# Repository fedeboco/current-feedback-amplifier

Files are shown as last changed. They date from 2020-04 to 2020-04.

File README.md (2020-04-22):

# Current Feedback Topology 40W Audio Amplifier

The current feedback topology gives this amplifier some independency between gain and bandwidth, resulting in an amplifier with relatively high power and high bandwidth (around 450 kHz at full power). Having a higher bandwidth than the traditional audio band (up to 20 kHz) produces a lower phase distortion in the audio band, consequently producing better sound.

##### Specifications achieved:
| Specification | Measured  |
| --- | -----: |
| Power (RMS) | 40 W |
| Power Bandwidth | 450 kHz |
| Bandwidth | 1MHz |
| SNR | 84 dB |
| THD (40W) | 0.2% |
| THD (1W) | 0.012% |
| IMD (1W) | -78 dB |
| Gain | 24.5 dB |

## Design

Heatsink has been designed using FreeCad and circuit using KiCad.

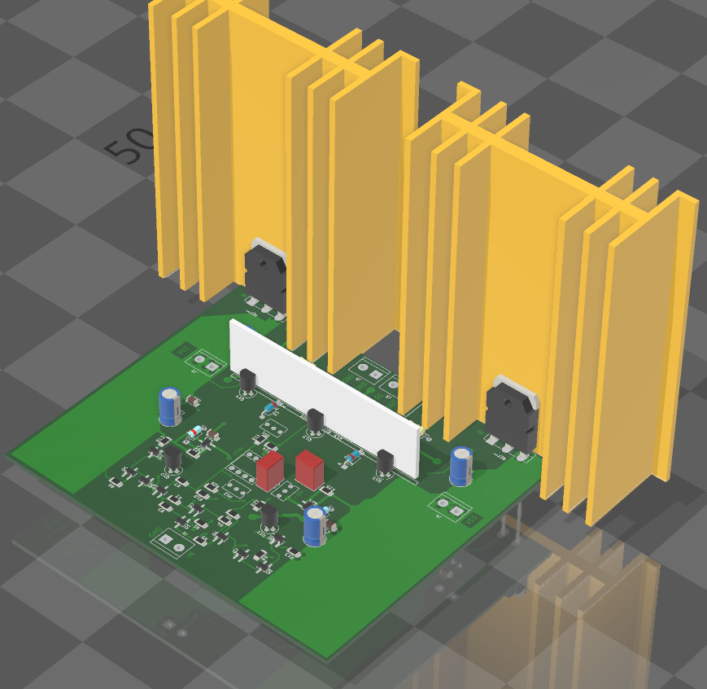
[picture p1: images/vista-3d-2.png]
![]()

## Schematic

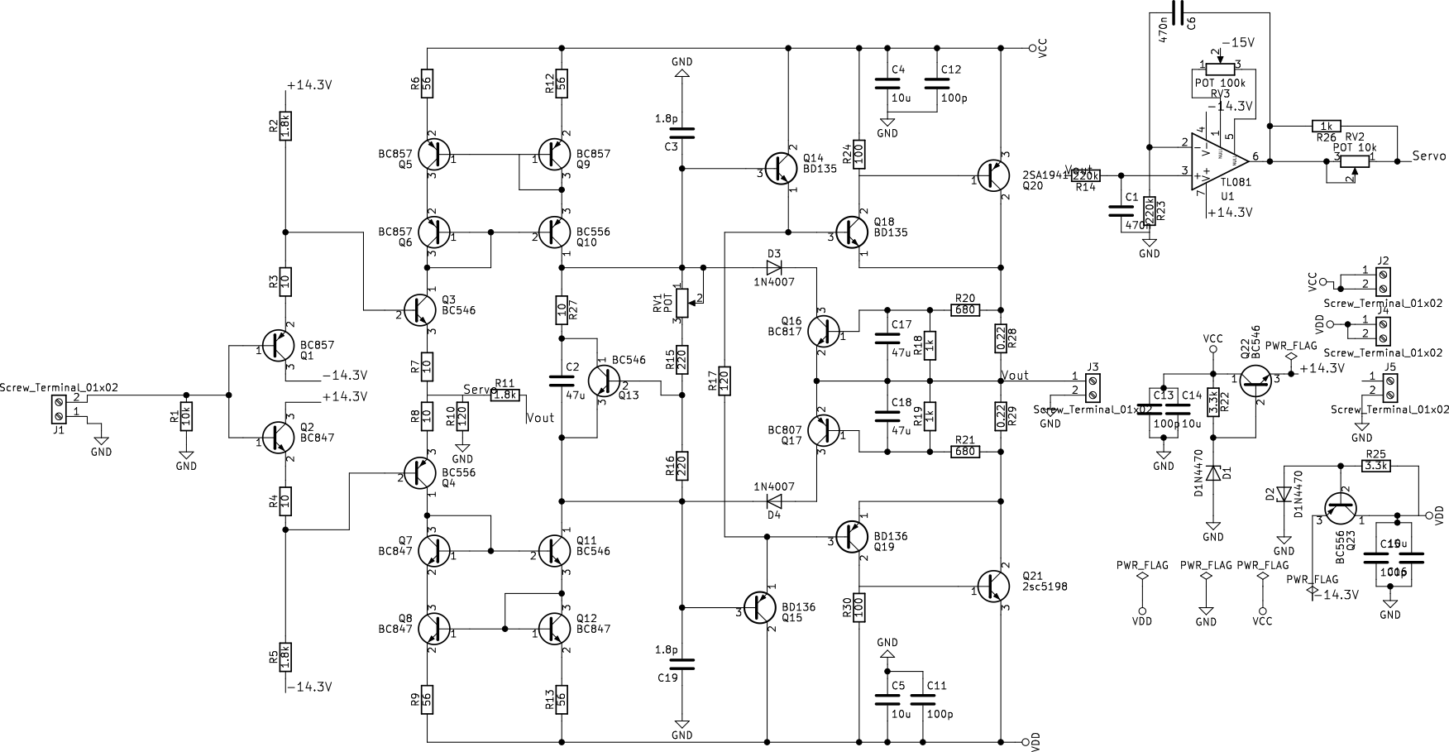
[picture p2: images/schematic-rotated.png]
![]()

## Total Harmonic Distortion Measured

Distortion did not exceed 0,2% at full power, rating at around 0,1% on average of frequencies.

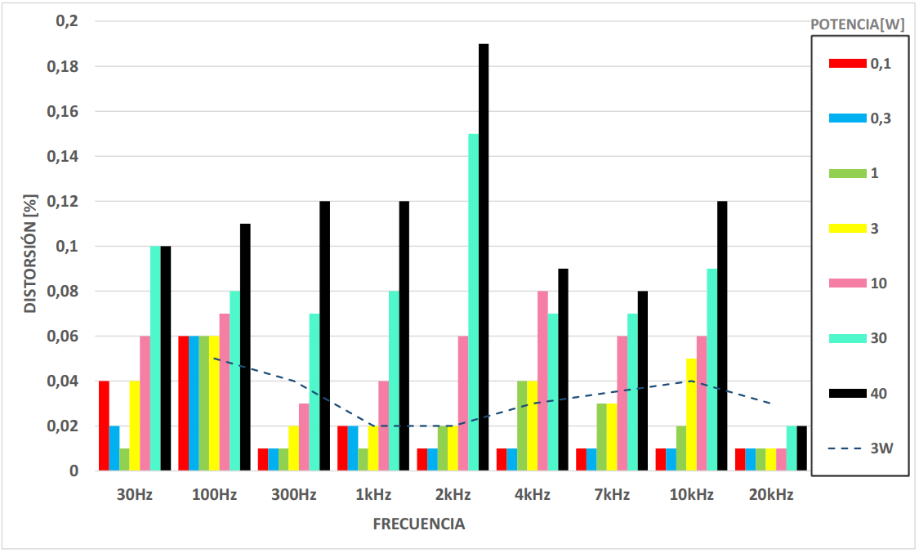
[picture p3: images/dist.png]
![]()

## Different views and base

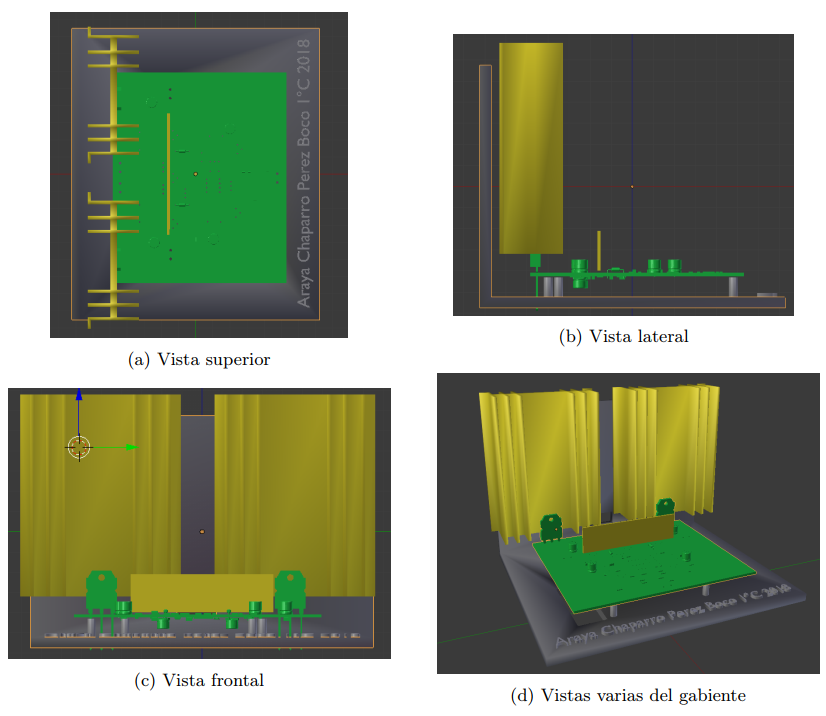
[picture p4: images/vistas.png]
![]()

## Previous Version

This version was bigger than the current version. It was also difficult to measure, more unstable and produced higher temperatures.

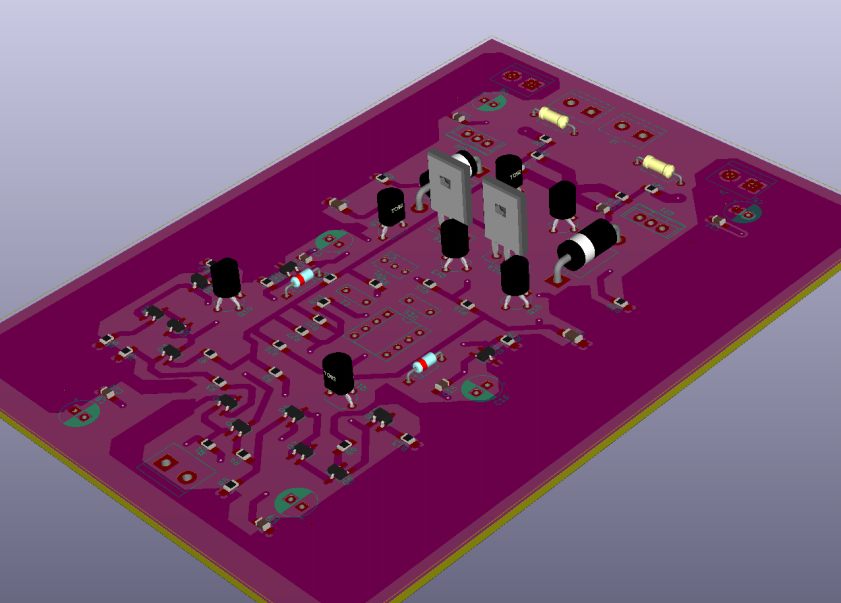
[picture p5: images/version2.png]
![]()

## PCB

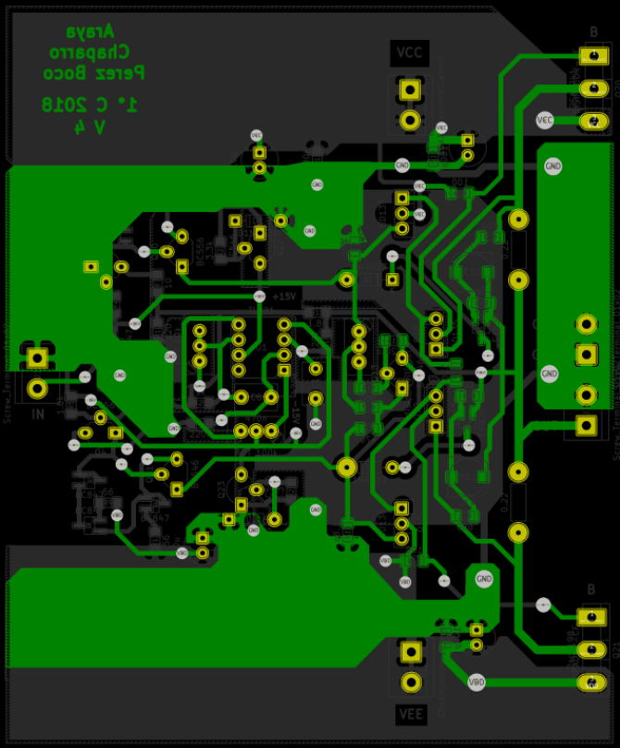
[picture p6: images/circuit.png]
![]()

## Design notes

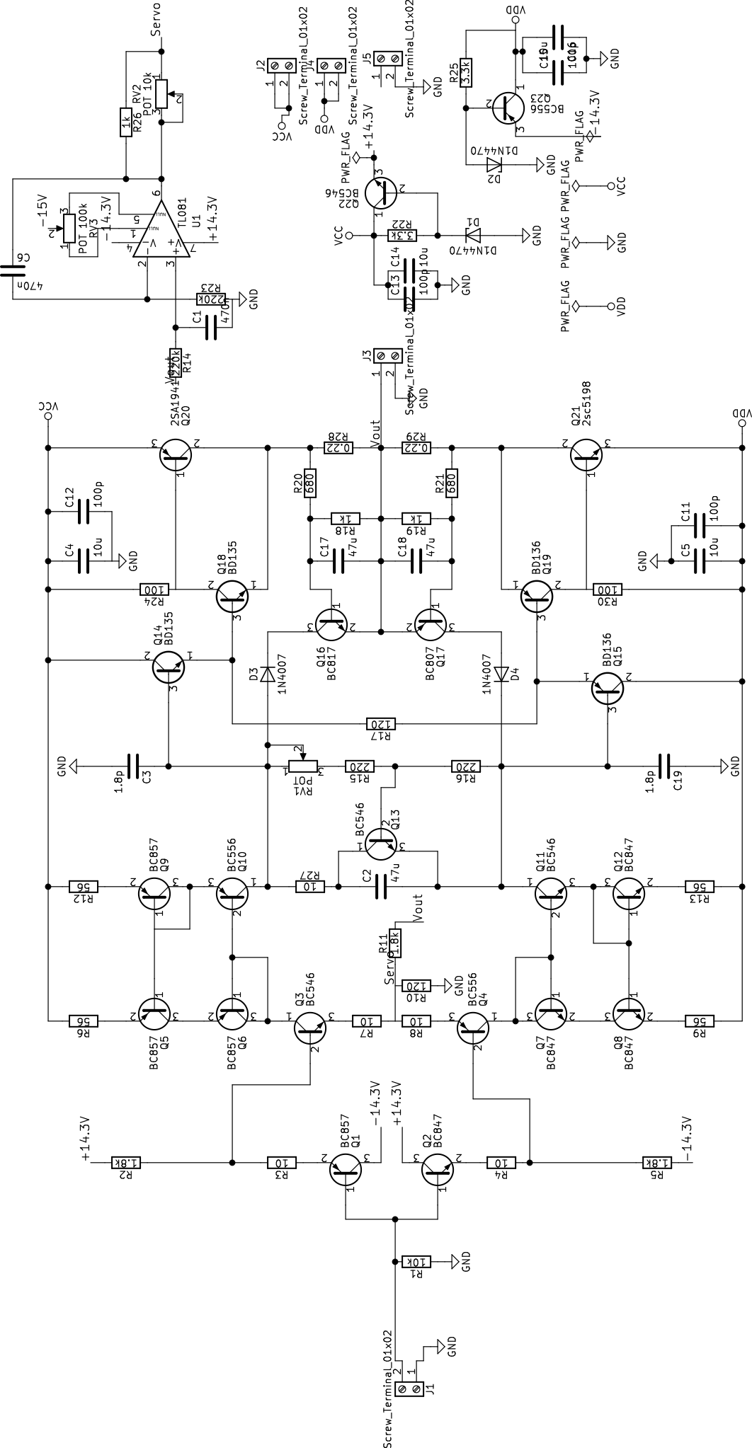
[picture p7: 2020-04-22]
images/schematic.png

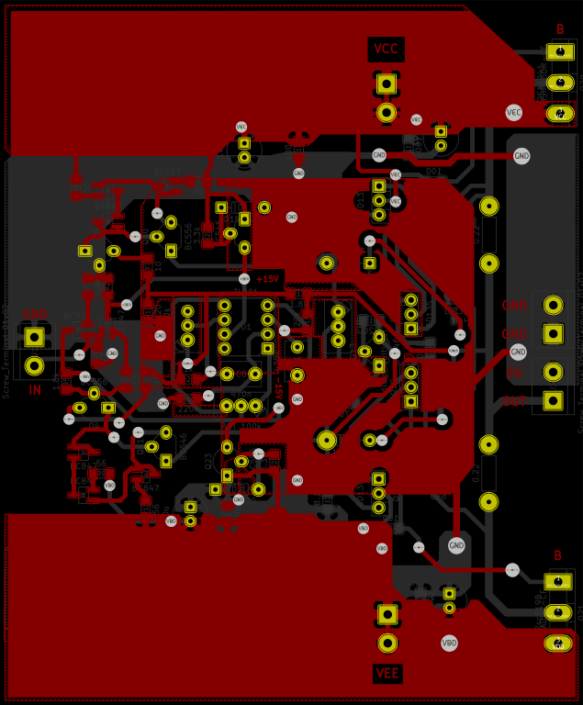
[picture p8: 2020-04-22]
schematic/VISTASUPERIOR.png

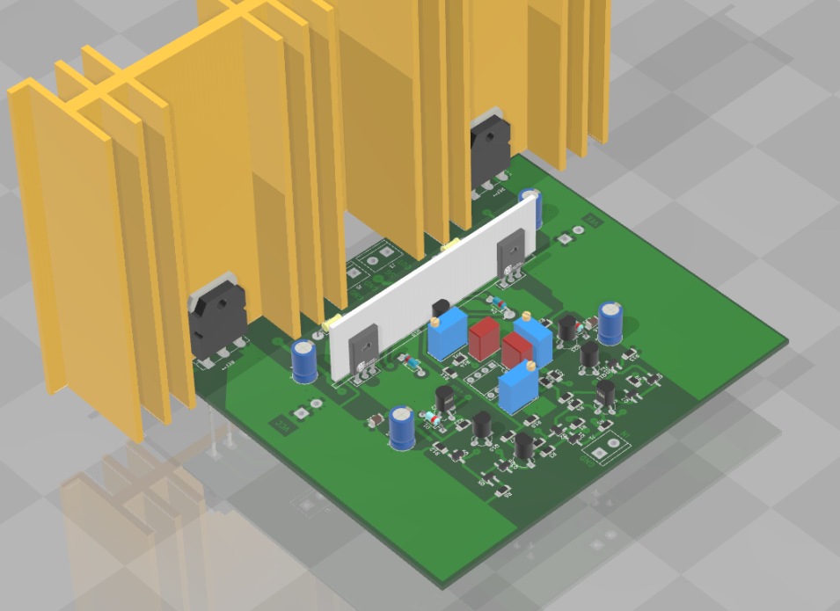
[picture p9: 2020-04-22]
images/vista-3d.png

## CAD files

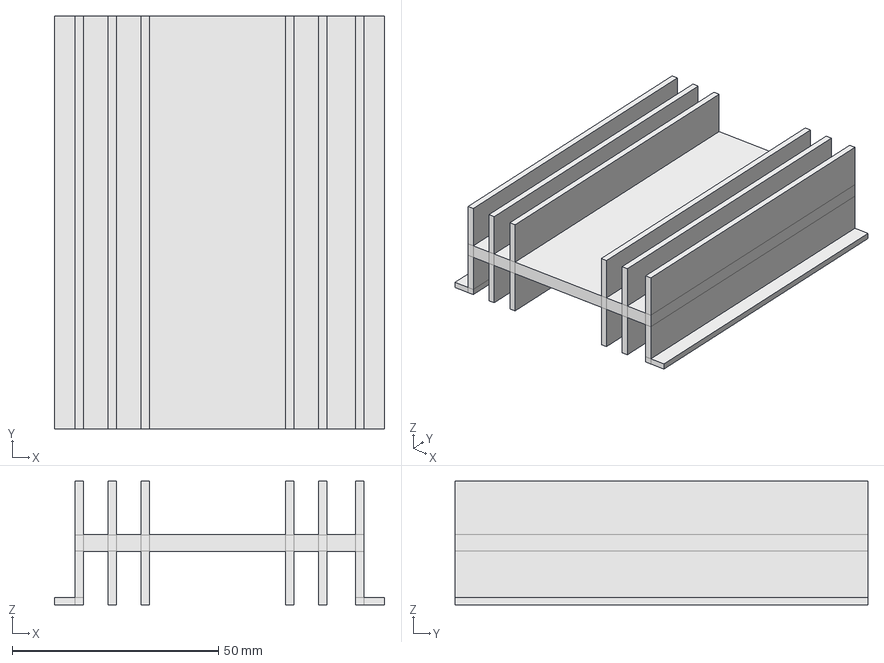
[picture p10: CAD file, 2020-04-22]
schematic/DISIPADOR/Disipador.FCStd
80.0 x 100.0 x 30.0 mm

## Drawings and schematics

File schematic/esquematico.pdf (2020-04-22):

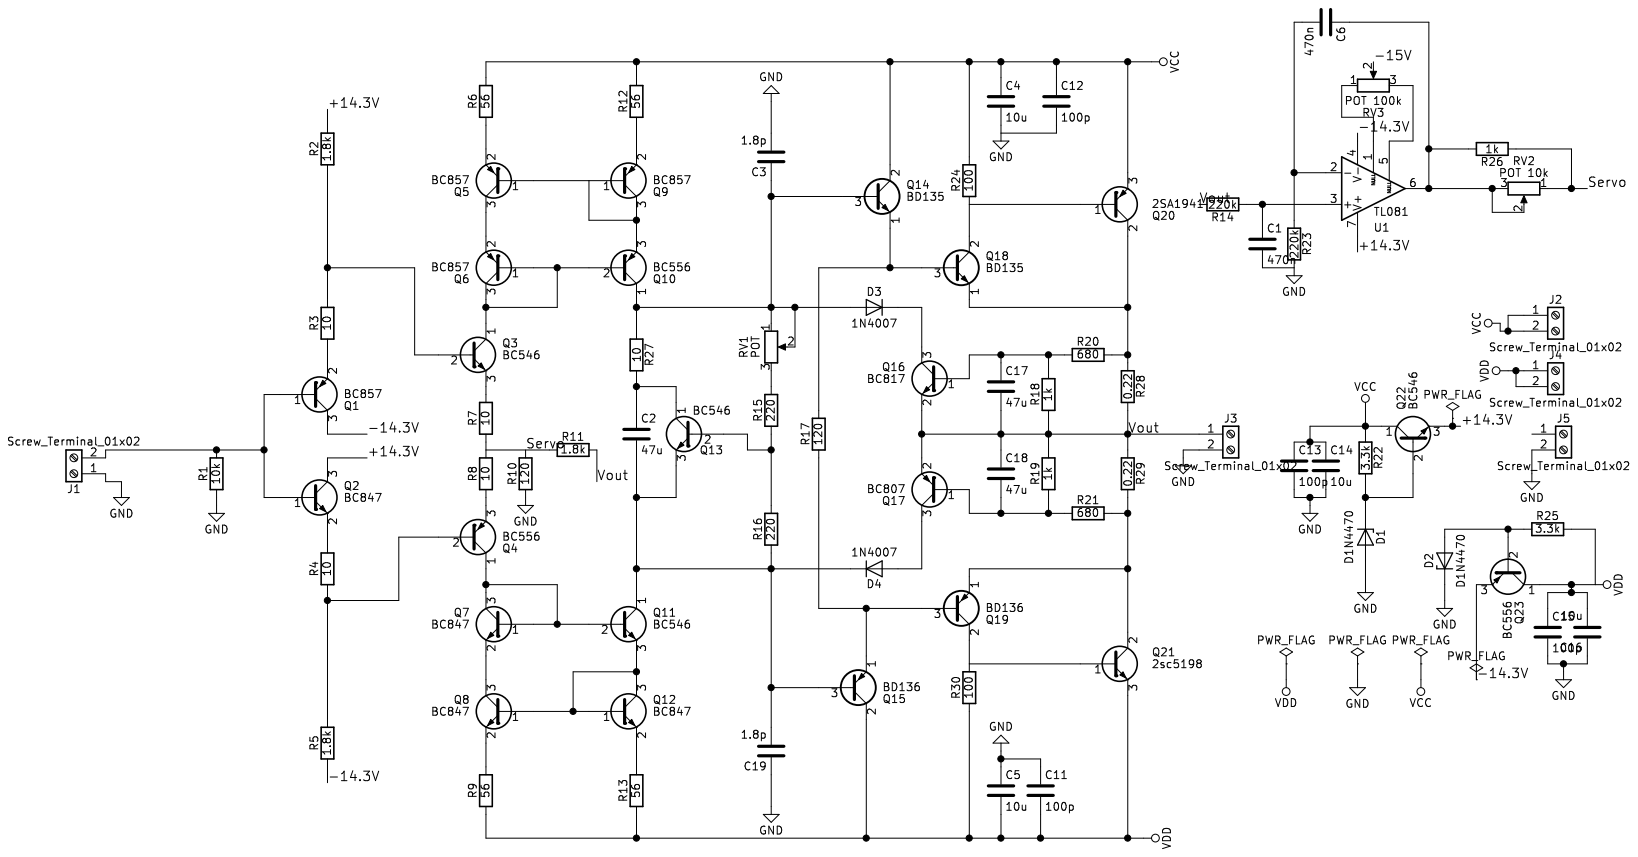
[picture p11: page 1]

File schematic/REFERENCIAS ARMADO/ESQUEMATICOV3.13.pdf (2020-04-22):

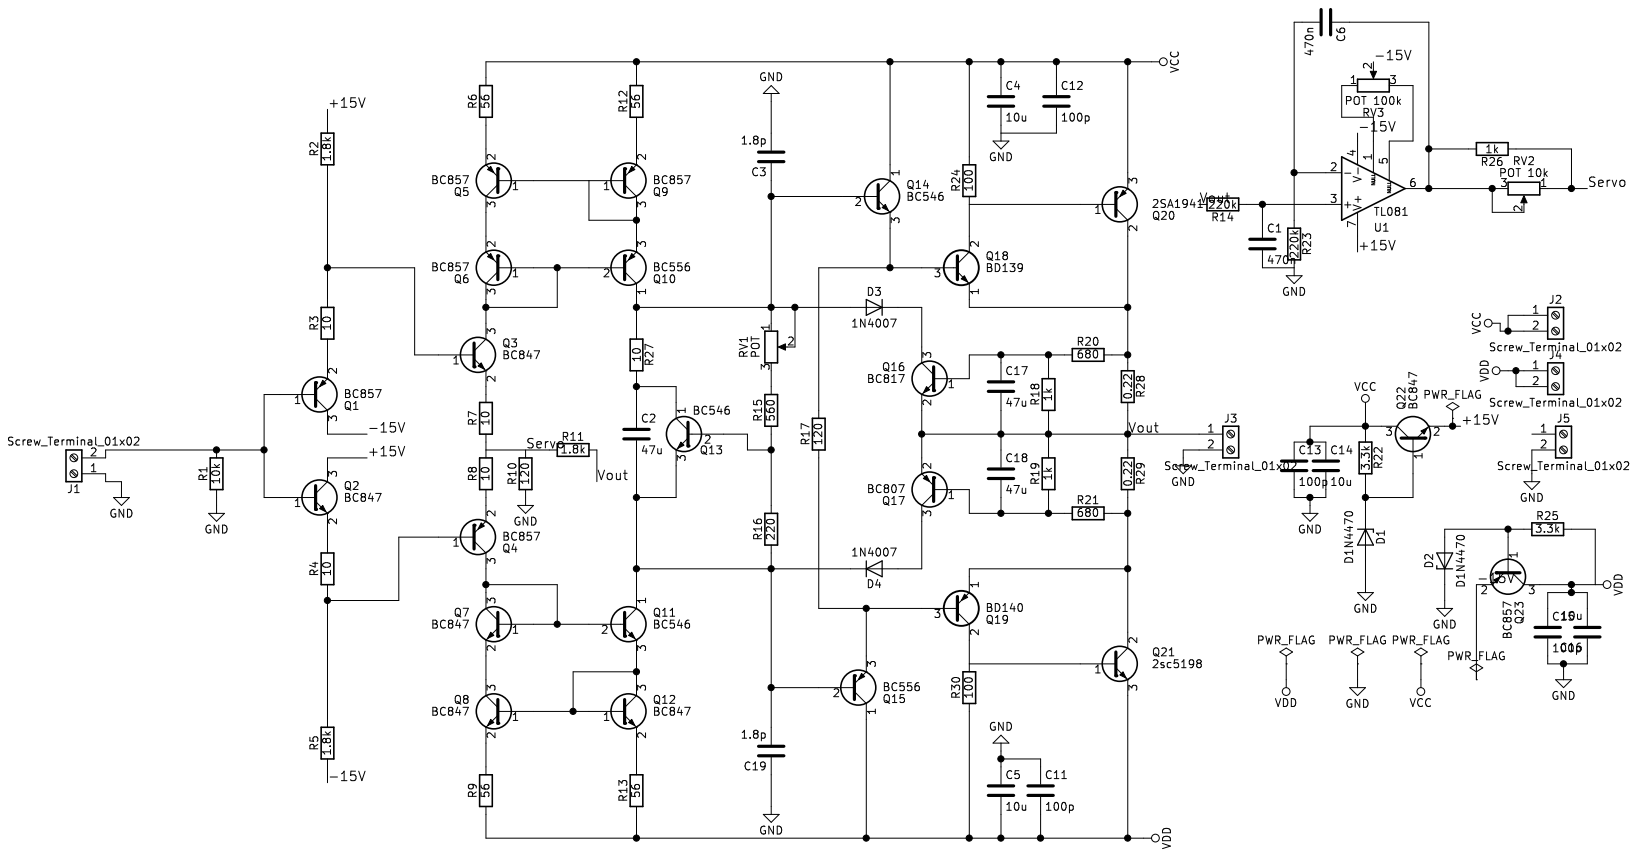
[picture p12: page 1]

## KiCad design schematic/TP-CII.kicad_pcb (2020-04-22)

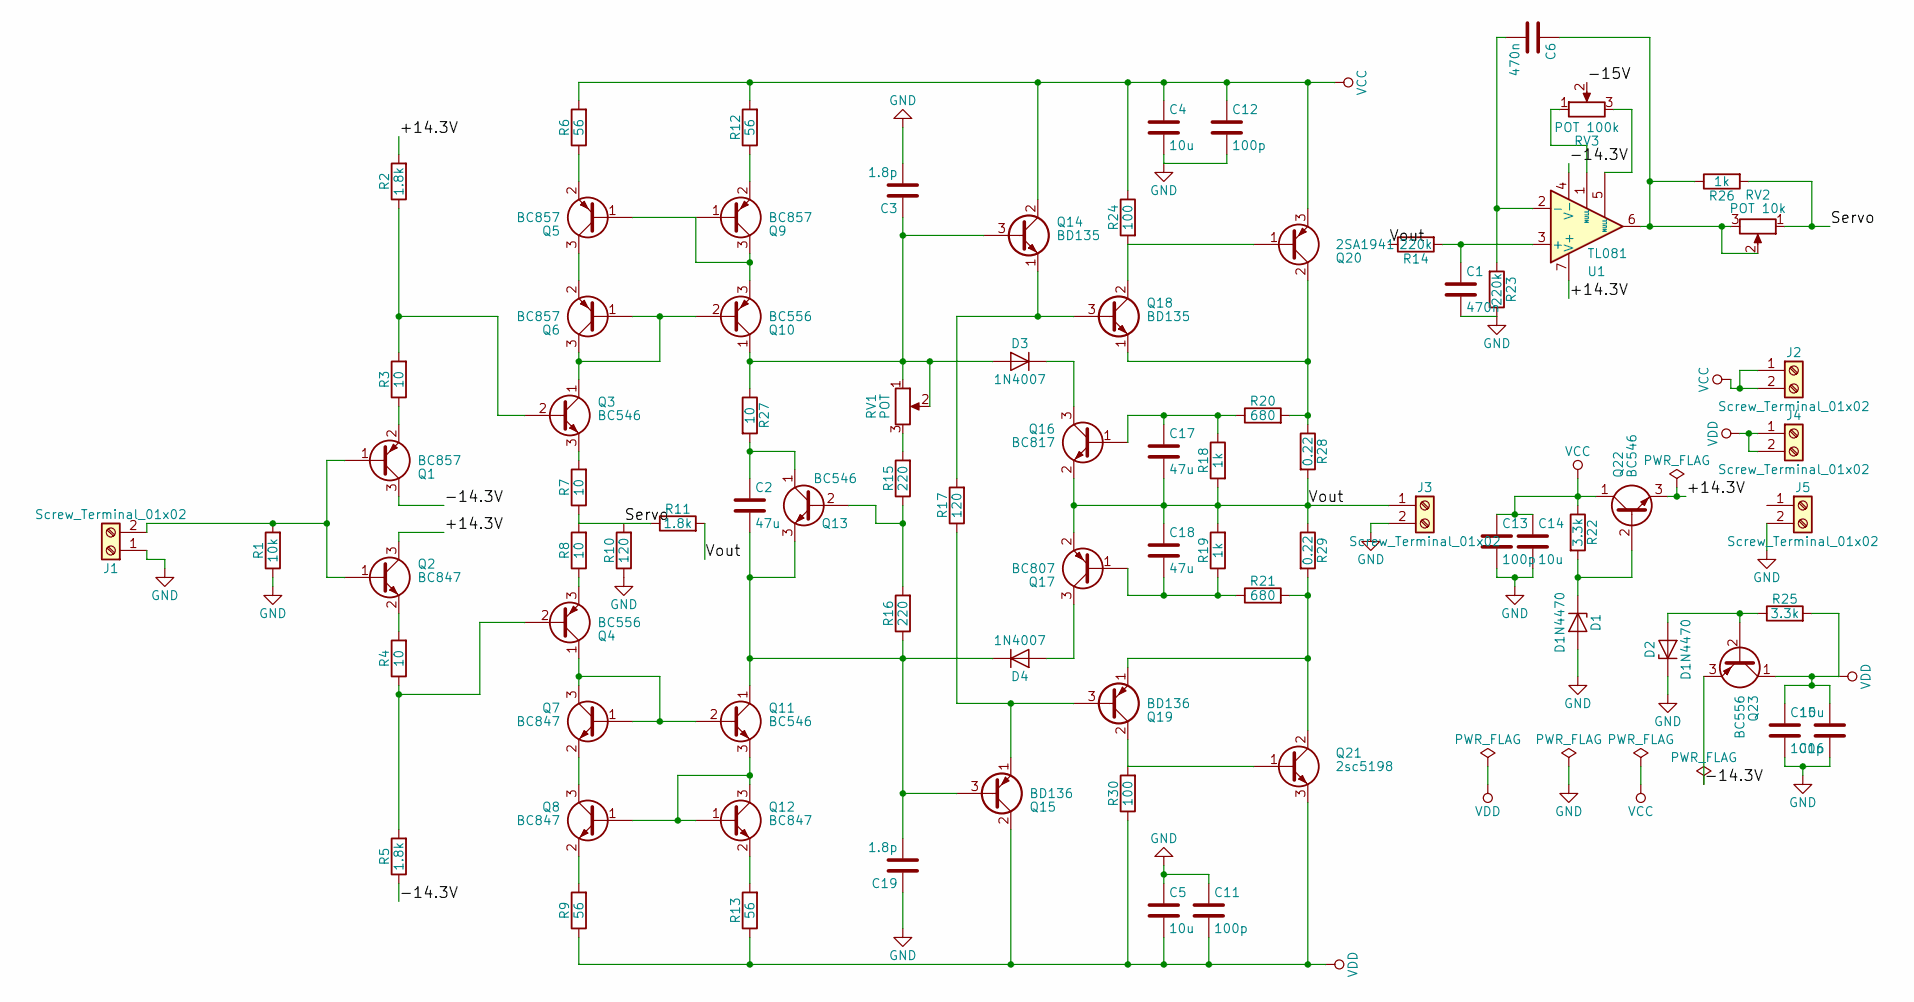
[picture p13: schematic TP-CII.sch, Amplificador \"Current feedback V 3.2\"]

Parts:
C1, C6: 470n; C_Rect_L9.0mm_W4.0mm_P7.50mm_MKT
C2: 47u; C_1206_3216Metric_Pad1.42x1.75mm_HandSolder
C3, C19: 1.8p; C_1206_3216Metric_Pad1.42x1.75mm_HandSolder
C4, C5, C14, C16: 10u; CP_Radial_D6.3mm_P2.50mm
C11, C12, C13, C15: 100p; C_1206_3216Metric_Pad1.42x1.75mm_HandSolder
C17, C18: 47u; CP_Elec_6.3x5.7
D1, D2: D1N4470; D_DO-35_SOD27_P7.62mm_Horizontal
D3, D4: 1N4007; D_DO-35_SOD27_P7.62mm_Horizontal
J1, J2, J3, J4, J5: Screw_Terminal_01x02; TerminalBlock_bornier-2_P5.08mm
Q1, Q5, Q6: BC857; TSOT-23_HandSoldering
Q2, Q7, Q8: BC847; TSOT-23_HandSoldering
Q3, Q11, Q13, Q22: BC546; TO-92
Q4, Q10, Q23: BC556; TO-92
Q9: BC857; SOT-23_Handsoldering
Q12: BC847; SOT-23_Handsoldering
Q14, Q18: BD135; TO-126_Vertical
Q15, Q19: BD136; TO-126_Vertical
Q16: BC817; TSOT-23_HandSoldering
Q17: BC807; TSOT-23_HandSoldering
Q20: 2SA1941; TO-3P-3_Vertical
Q21: 2sc5198; TO-3P-3_Vertical
R1: 10k; R_1206_3216Metric_Pad1.42x1.75mm_HandSolder
R2, R5, R11: 1.8k; R_1206_3216Metric_Pad1.42x1.75mm_HandSolder
R3, R4, R7, R8, R27: 10; R_1206_3216Metric_Pad1.42x1.75mm_HandSolder
R6, R9, R12, R13: 56; R_1206_3216Metric_Pad1.42x1.75mm_HandSolder
R10, R17: 120; R_1206_3216Metric_Pad1.42x1.75mm_HandSolder
R14, R23: 220k; R_1206_3216Metric_Pad1.42x1.75mm_HandSolder
R15, R16: 220; R_1206_3216Metric_Pad1.42x1.75mm_HandSolder
R18, R19, R26: 1k; R_1206_3216Metric_Pad1.42x1.75mm_HandSolder
R20, R21: 680; R_1206_3216Metric_Pad1.42x1.75mm_HandSolder
R22, R25: 3.3k; R_1206_3216Metric_Pad1.42x1.75mm_HandSolder
R24, R30: 100; R_1206_3216Metric_Pad1.42x1.75mm_HandSolder
R28, R29: 0.22; R_Axial_DIN0207_L6.3mm_D2.5mm_P10.16mm_Horizontal
RV1: POT; Potentiometer_Bourns_3266Y_Vertical
RV2: POT 10k; Potentiometer_Bourns_3266Y_Vertical
RV3: POT 100k; Potentiometer_Bourns_3266Y_Vertical
U1: TL081; DIP-8_W7.62mm_Socket

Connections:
/+15V: Q2.3 (C), Q22.3 (E), R2.2, U1.7 (V+)
/Servo: R7.1, R8.2, R10.2, R11.1, R26.2, RV2.1
/Vout: C17.2, C18.1, J3.1, Q16.2 (E), Q17.2 (E), R11.2, R14.1, R18.2, R19.2, R28.2, R29.1
GND: C1.2, C3.2, C4.2, C5.1, C11.1, C12.2, C13.2, C14.2, C15.2, C16.1, C19.1, D1.2 (A), D2.1 (K), J1.1, J3.2, J5.2, R1.1, R10.1, R23.1; also elsewhere on the board
unnamed: C1.1, R14.2, U1.3 (+)
unnamed: C2.1, Q13.1 (C), R27.2
unnamed: C3.1, D3.2 (A), Q10.1 (C), Q14.3 (B), R27.1, RV1.1, RV1.2
unnamed: C6.1, R26.1, RV2.2, RV2.3, U1.6
unnamed: C6.2, R23.2, U1.2 (-)
unnamed: C17.1, Q16.1 (B), R18.1, R20.1
unnamed: C18.2, Q17.1 (B), R19.1, R21.1
unnamed: C2.2, C19.2, D4.1 (K), Q11.1 (C), Q13.3 (E), Q15.3 (B), R16.1
unnamed: D1.1 (K), Q22.2 (B), R22.2
unnamed: D2.2 (A), Q23.2 (B), R25.1
unnamed: D3.1 (K), Q16.3 (C)
unnamed: D4.2 (A), Q17.3 (C)
unnamed: J1.2, Q1.1 (B), Q2.1 (B), R1.2
unnamed: Q1.2 (E), R3.1
unnamed: Q2.2 (E), R4.2
unnamed: Q3.2 (B), R2.1, R3.2
unnamed: Q3.3 (E), R7.2
unnamed: Q4.2 (B), R4.1, R5.2
unnamed: Q4.3 (E), R8.1
unnamed: Q5.2 (E), R6.1
unnamed: Q5.3 (C), Q6.2 (E)
unnamed: Q7.2 (E), Q8.3 (C)
unnamed: Q8.2 (E), R9.2
unnamed: Q9.2 (E), R12.1
unnamed: Q3.1 (C), Q6.1 (B), Q6.3 (C), Q10.2 (B)
unnamed: Q5.1 (B), Q9.1 (B), Q9.3 (C), Q10.3 (E)
unnamed: Q4.1 (C), Q7.1 (B), Q7.3 (C), Q11.2 (B)
unnamed: Q8.1 (B), Q11.3 (E), Q12.1 (B), Q12.3 (C)
unnamed: Q12.2 (E), R13.2
unnamed: Q13.2 (B), R15.1, R16.2
unnamed: Q14.1 (E), Q18.3 (B), R17.2
unnamed: Q15.1 (E), Q19.3 (B), R17.1
unnamed: Q18.1 (E), Q20.2 (C), R20.2, R28.1
unnamed: Q18.2 (C), Q20.1 (B), R24.2
unnamed: Q19.1 (E), Q21.2 (C), R21.2, R29.2
unnamed: Q19.2 (C), Q21.1 (B), R30.2
unnamed: R15.2, RV1.3
unnamed: RV3.1, U1.1 (NULL)
unnamed: RV3.3, U1.5 (NULL)
VCC: C4.1, C12.1, C13.1, C14.1, J2.1, J2.2, Q14.2 (C), Q20.3 (E), Q22.1 (C), R6.2, R12.2, R22.1, R24.1; also elsewhere on the board
VDD: C5.2, C11.2, C15.1, C16.2, J4.1, J4.2, Q15.2 (C), Q21.3 (E), Q23.1 (C), R9.1, R13.1, R25.2, R30.1

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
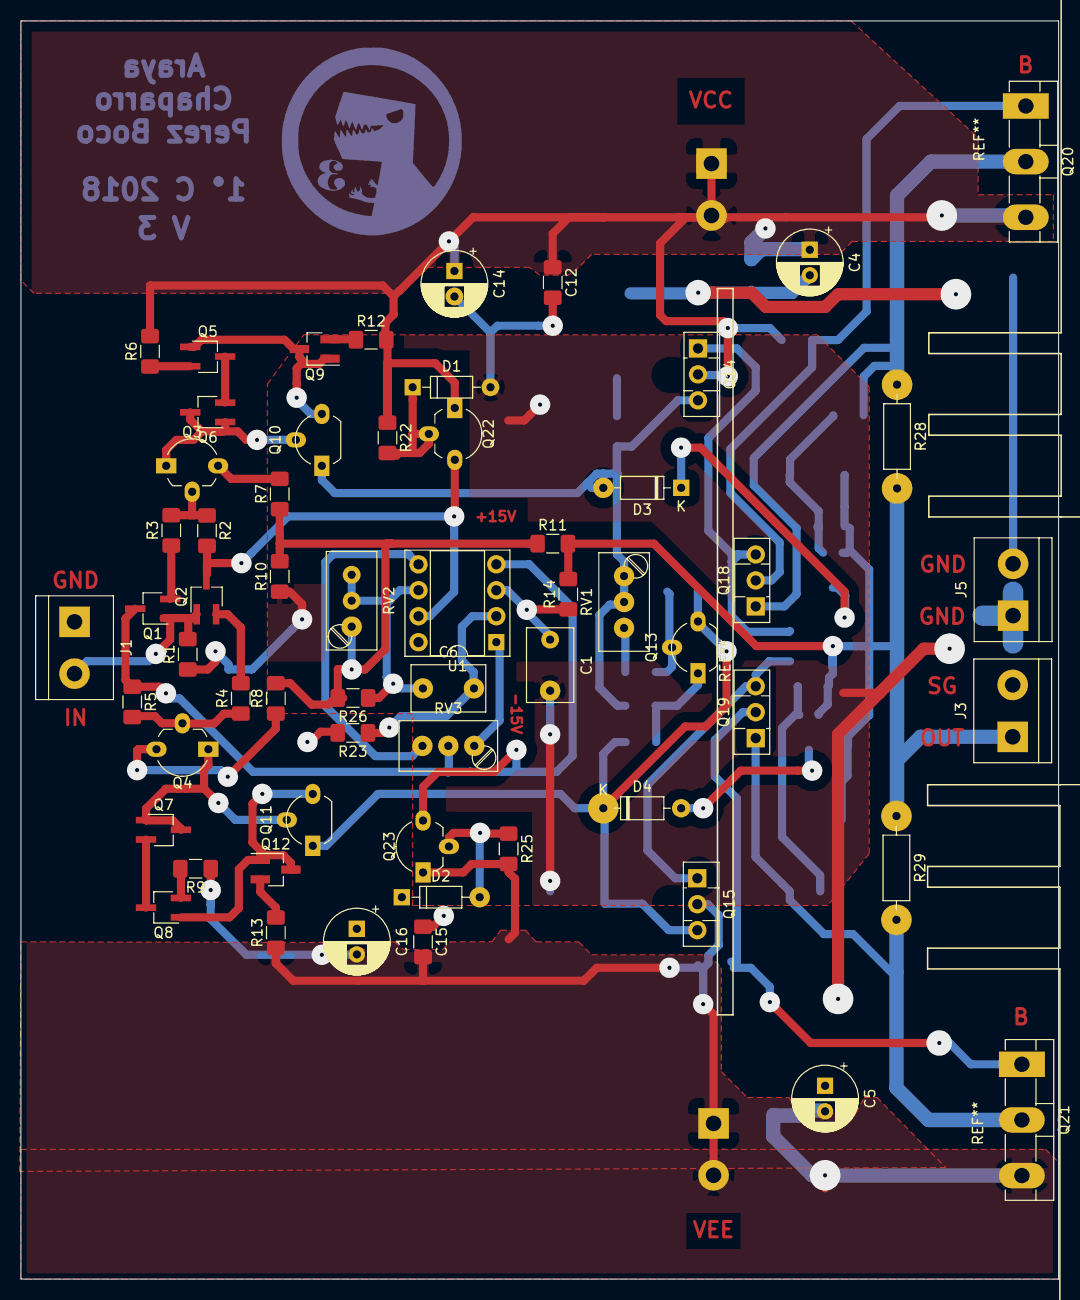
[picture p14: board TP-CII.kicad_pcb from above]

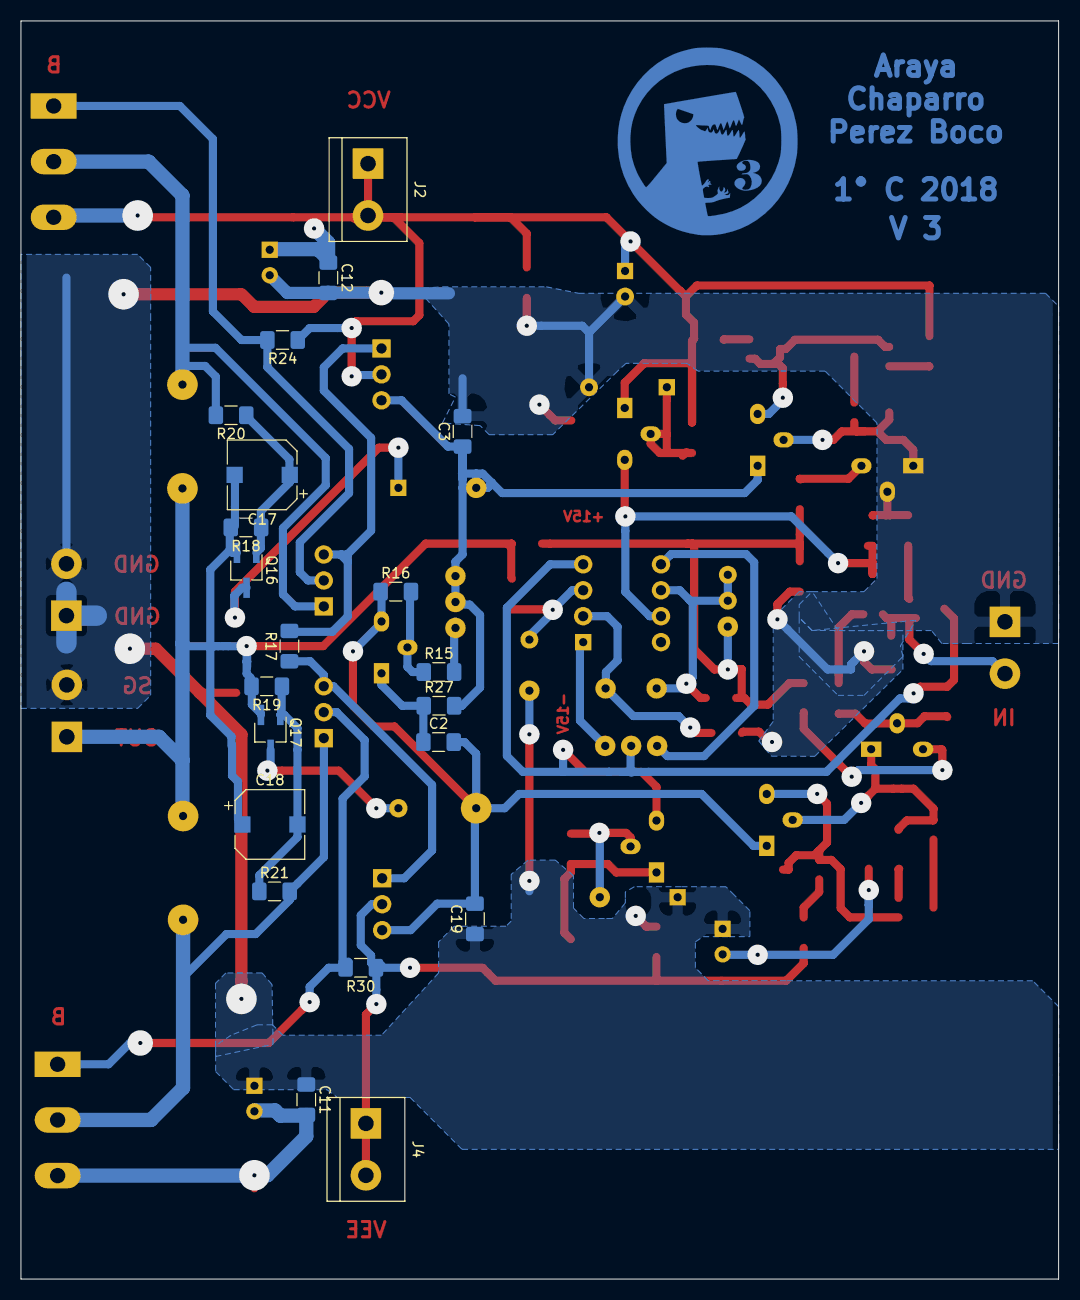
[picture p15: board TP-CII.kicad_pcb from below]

Board: 2 copper layers, 101.6 x 123.2 mm, 81 parts (21 on the bottom side), 46 nets.

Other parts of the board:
C12#2: 100p; C_1206_3216Metric_Pad1.42x1.75mm_HandSolder

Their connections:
GND: C12#2.2; also elsewhere on the board
VCC: C12#2.1; also elsewhere on the board

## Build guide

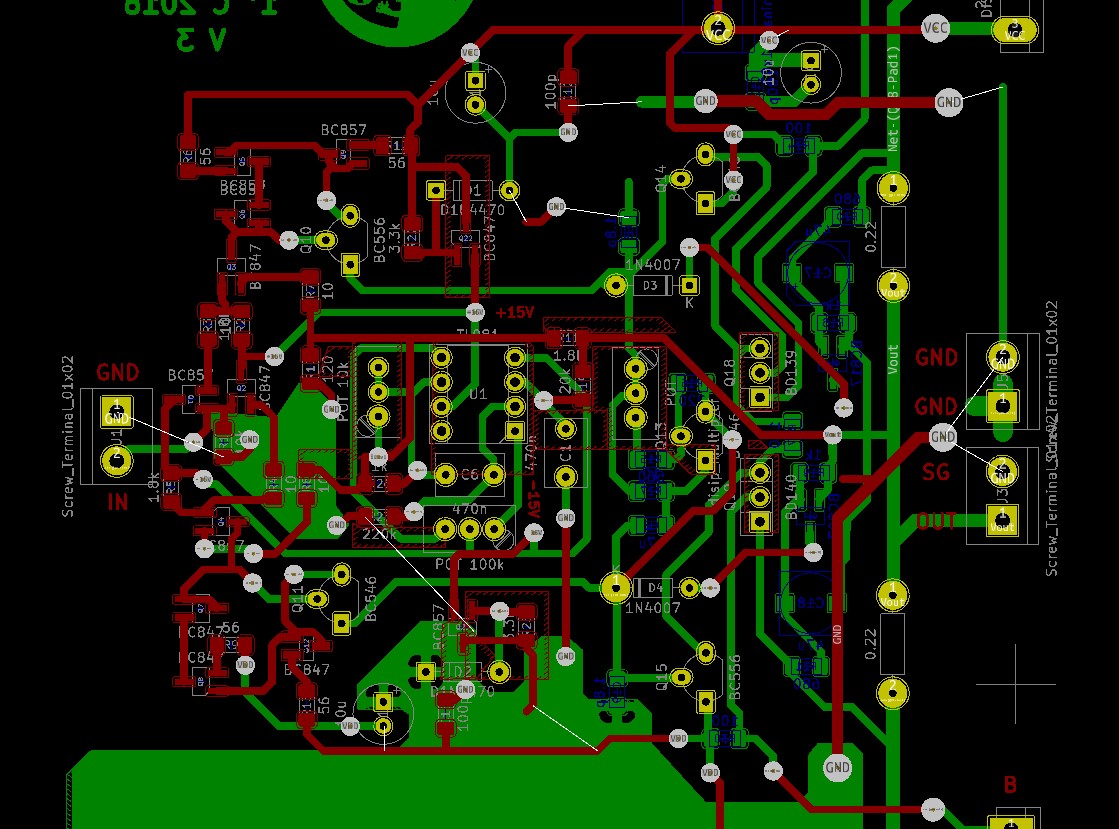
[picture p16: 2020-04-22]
schematic/REFERENCIAS ARMADO/VISTAPCBV3.13.jpg

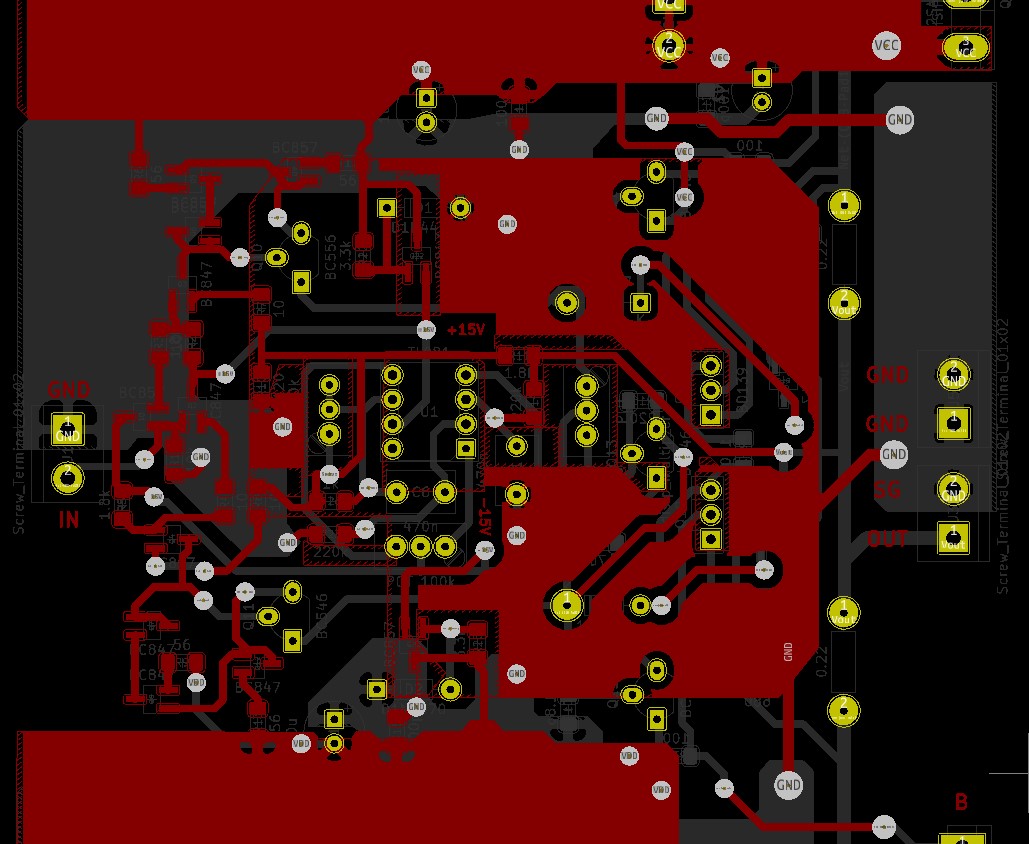
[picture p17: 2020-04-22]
schematic/REFERENCIAS ARMADO/VISTAPCBHCFRONTV3.13.jpg

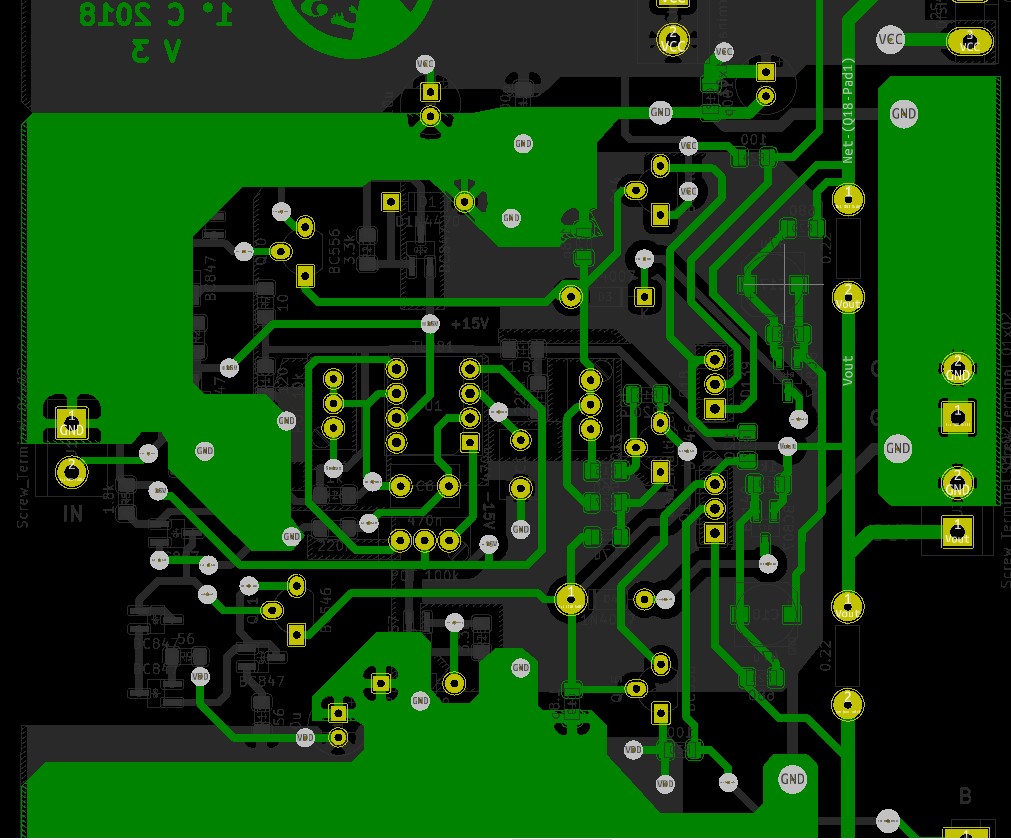
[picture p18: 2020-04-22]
schematic/REFERENCIAS ARMADO/VISTAPCBHCBACKV3.13.jpg
